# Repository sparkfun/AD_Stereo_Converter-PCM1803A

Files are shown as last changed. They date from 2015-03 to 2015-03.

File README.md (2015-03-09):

SparkFun Analog to Digital Stereo Converter Breakout - PCM1803A
===============================================================

SparkFun Analog to Digital Stereo Converter Breakout - PCM1803A

[*SparkFun Analog to Digital Stereo Converter Breakout - PCM1803A (BOB-09365)*](https://www.sparkfun.com/products/9365)

The PCM1803A is a high-performance, low-cost, 24-bit stereo analog-to-digital converter that can sample as high as 96k. 
The PCM1803A is a great choice for a wide variety of applications where high performance is necessary. 

Repository Contents
-------------------
* **/Firmware** - Example code 
* **/Hardware** - All Eagle design files (.brd, .sch)

License Information
-------------------
The hardware is released under [Creative Commons ShareAlike 4.0 International](https://creativecommons.org/licenses/by-sa/4.0/).
The code is beerware; if you see me (or any other SparkFun employee) at the local, and you've found our code helpful, please buy us a round!

Distributed as-is; no warranty is given.

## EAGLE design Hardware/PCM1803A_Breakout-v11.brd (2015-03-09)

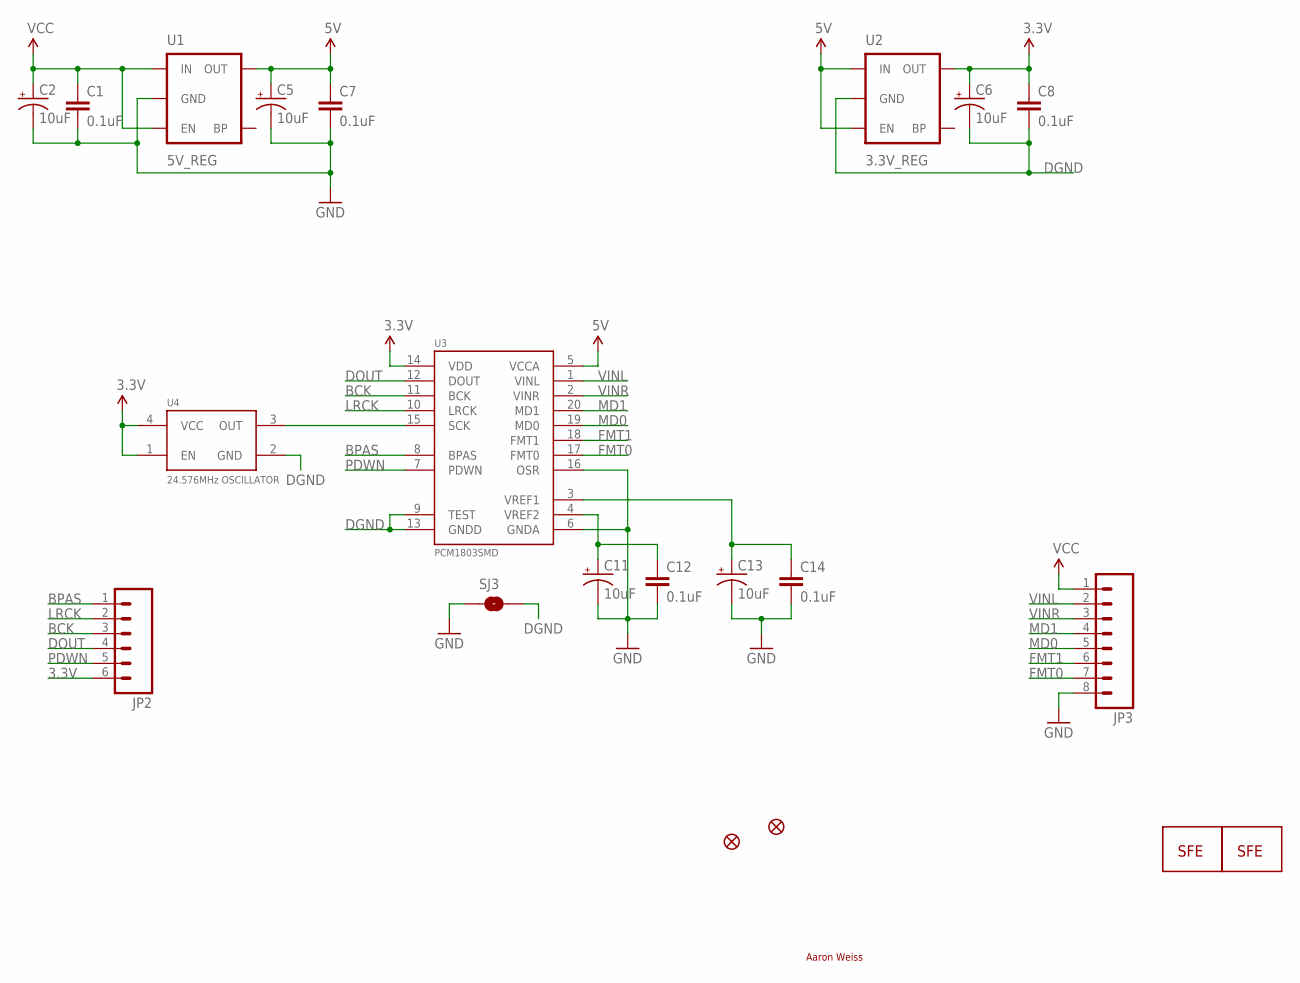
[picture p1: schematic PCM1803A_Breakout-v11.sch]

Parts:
C1, C7, C8, C12, C14: 0.1uF; 0402-CAP
C2, C5, C6, C11, C13: 10uF; EIA3216
JP1: LOGO-SFESK; SFE-LOGO-FLAME
JP2: M06SIP; 1X06
JP3: M08; 1X08
JP4, JP5: FIDUCIAL1X2; FIDUCIAL-1X2
SJ3: SOLDERJUMPERTRACE; SJ_2S-TRACE
U1: 5V_REG; SOT23-5
U2: 3.3V_REG; SOT23-5
U3: PCM1803SMD; SSOP20
U4: 24.576MHz OSCILLATOR; CRYSTAL-SMD-7.5X5.2-6PIN
U$4: LOGO-SFENEW; SFE-NEW-WEBLOGO

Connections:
3.3V: C6.A (+), C8.1, JP2.6, U2.5 (OUT), U3.14 (VDD), U4.1 (EN), U4.4 (VCC)
5V: C5.A (+), C7.1, U1.5 (OUT), U2.1 (IN), U2.3 (EN), U3.5 (VCCA)
BCK: JP2.3, U3.11 (BCK)
BPAS: JP2.1, U3.8 (BPAS)
DGND: C6.C (-), C8.2, SJ3.2, U2.2 (GND), U3.9 (TEST), U3.13 (GNDD), U4.2 (GND)
DOUT: JP2.4, U3.12 (DOUT)
FMT0: JP3.7, U3.17 (FMT0)
FMT1: JP3.6, U3.18 (FMT1)
GND: C1.2, C2.C (-), C5.C (-), C7.2, C11.C (-), C12.2, C13.C (-), C14.2, JP3.8, SJ3.1, U1.2 (GND), U3.6 (GNDA), U3.16 (OSR)
LRCK: JP2.2, U3.10 (LRCK)
MD0: JP3.5, U3.19 (MD0)
MD1: JP3.4, U3.20 (MD1)
unnamed: U3.15 (SCK), U4.3 (OUT)
unnamed: C11.A (+), C12.1, U3.4 (VREF2)
unnamed: C13.A (+), C14.1, U3.3 (VREF1)
PDWN: JP2.5, U3.7 (PDWN)
VCC: C1.1, C2.A (+), JP3.1, U1.1 (IN), U1.3 (EN)
VINL: JP3.2, U3.1 (VINL)
VINR: JP3.3, U3.2 (VINR)

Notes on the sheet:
Aaron Weiss

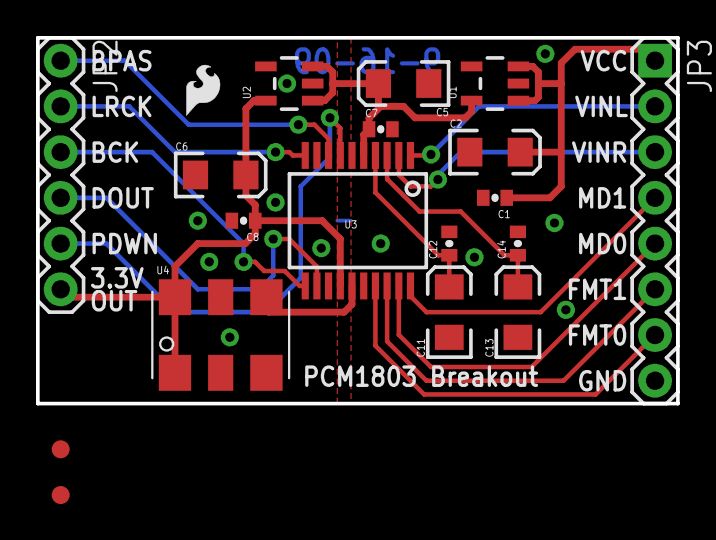
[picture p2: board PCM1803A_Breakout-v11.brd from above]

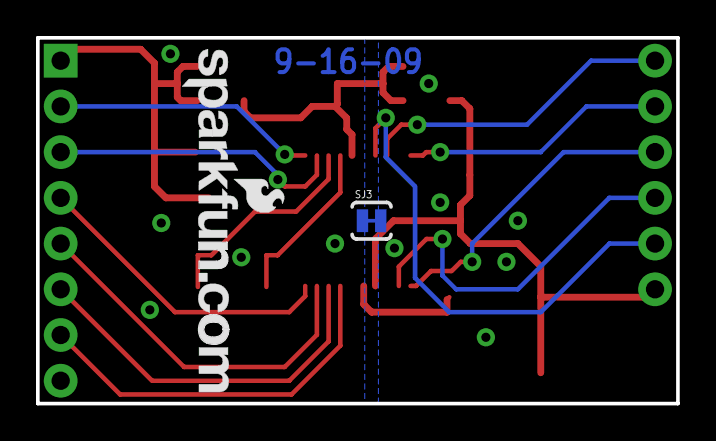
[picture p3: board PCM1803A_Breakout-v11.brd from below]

Board: 2 copper layers, 35.6 x 20.3 mm, 21 parts (2 on the bottom side), 19 nets.

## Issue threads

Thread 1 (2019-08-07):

Help required re Code and wiring with Raspberry Pi

ravimiranda, 2019-08-07:
Hi,
Are there any help notes, advice, wiring diagram on using the Sparkfun Stereo Converter - PCM1803A with Raspbery Pi?

Many thanks

loricrotser, 2019-10-01:
Hi! Unfortunately, it doesn't look like we have anything in-house that addresses this specifically. The retired product page is still available (https://www.sparkfun.com/products/retired/9365) and that has the datasheet and Eagle Files/Schematic, but I think your best bet here is to try the Forums. Our tech support team should be able to point you in the right direction.

Hopefully that is helpful.

Closed 2019-10-01.

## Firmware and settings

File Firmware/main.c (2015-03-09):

/*
    10-1-09
	Copyright Spark Fun Electronics© 2009
    Aaron Weiss
	aaron@sparkfun.com
	
	PCM1803A 24bit ADC
    
	*ATMega168 running @ 20MHz (High fuse = 0xDF, Low fuse = 0xE6)
	*Analog inputs are 3VPP tollerant
	*Using ATMega SPI interface in slave mode
	*This code only works on one channel, i.e. when LRCK = 0
	*Must have analog inputs connected if using one channel
	*ADC hardware configuration
	 Master Mode (512f and 384f only work)
	 Mode0:1 
	 Mode1:0
	
	 Left-justified 24-bit
	 Format0:0
	 Format1:0
	
	 PWDN:1
	 BPAs:1
*/

#include <stdlib.h>
#include <stdio.h>
#include <avr/io.h>

#define FOSC 20000000
#define BAUD 9600
#define MYUBRR 129 

#define sbi(var, mask)   ((var) |= (uint8_t)(1 << mask))
#define cbi(var, mask)   ((var) &= (uint8_t)~(1 << mask))

#define STATUS_LED 5

///===========Main Prototypes=============================///////////////////////
long read_ADC(void); //grab the 24 bits and concatenate each byte
long SPI_SlaveReceive(void); //wait for a 8bit transmission to complete and read SPDR register
void wait_to_start(void); // make sure we take the correct bits

///============Initialize Prototypes=====================///////////////////////
void ioinit(void);   
static int uart_putchar(char c, FILE *stream);
uint8_t uart_getchar(void);
static FILE mystdout = FDEV_SETUP_STREAM(uart_putchar, NULL, _FDEV_SETUP_WRITE);
void delay(uint16_t x);

/////===========Global Vars=============================////////////////////////
long out, csb, lsb, msb, dumby;

////////////////////////////////////////////////////////////////////////////////
//=========MAIN================/////////////////////////////////////////////////
////////////////////////////////////////////////////////////////////////////////
int main(void)
{	
	ioinit(); //Setup IO pins and defaults
	
	while(1)
	{	
		wait_to_start();
		read_ADC();
		
		printf("%lu \r\n",read_ADC());
	}
}

long read_ADC(void)
{
	dumby = SPI_SlaveReceive(); //start clocking back bits after the last transmission 
	msb = SPI_SlaveReceive(); //load msb first 
	csb = SPI_SlaveReceive(); //load second 8 bit segment
	lsb = SPI_SlaveReceive(); //load lsb last
	
	return out = lsb|(csb << 8)|(msb << 16); //concatenate each 8 bit segment
}

long SPI_SlaveReceive(void)
{
	while(!(SPSR & (1<<SPIF)));
	return SPDR;
}

void wait_to_start(void)
{
	while(!(PINB & (1 << PINB2)));//wait while LRCK is low
}

////////////////////////////////////////////////////////////////////////////////
///==============Initializations=======================================/////////
////////////////////////////////////////////////////////////////////////////////
void ioinit (void)
{
    //1 = output, 0 = input
    DDRB = 0b00010000; //PB4 = MISO 
    DDRC = 0b00110001; //Output on PORTC0, PORTC4 (SDA), PORTC5 (SCL), all others are inputs
    DDRD = 0b11110010; //PORTD (RX on PD0), input on PD2
	
    //USART Baud rate: 9600
    UBRR0H = MYUBRR >> 8;
    UBRR0L = MYUBRR;
    UCSR0B = (1<<RXEN0)|(1<<TXEN0);    
	
	stdout = &mystdout; //Required for printf init
	
	//initialize SPI slave
	SPCR = (1<<SPE);
}

static int uart_putchar(char c, FILE *stream)
{
    if (c == '\n') uart_putchar('\r', stream);
  
    loop_until_bit_is_set(UCSR0A, UDRE0);
    UDR0 = c;
    
    return 0;
}

uint8_t uart_getchar(void)
{
    while( !(UCSR0A & (1<<RXC0)) );
    return(UDR0);
}

void delay(uint16_t x)
{
  uint8_t y;
  for ( ; x > 0 ; x--){
    for ( y = 0 ; y < 50 ; y++){ 
    asm volatile ("nop");
    }
  }
}
